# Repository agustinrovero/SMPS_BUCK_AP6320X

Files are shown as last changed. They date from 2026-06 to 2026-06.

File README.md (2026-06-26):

# Mini 2A Buck Converter SMPS (AP6320X Family)

This repository contains the hardware design files in **KiCad** for an ultra-compact, high-efficiency **2A synchronous buck (step-down) converter**. The board layout is fully compatible with all four variants of the **AP6320X** integrated circuit from Diodes Incorporated, allowing the same PCB to be populated for different switching frequencies, operating modes, and output voltages.

## Technical Specifications

* **Input Voltage Range ($V_{IN}$):** 3.8 V to 32 V
* **Continuous Output Current ($I_{OUT}$):** 2 A
* **EMI Optimization:** Features Frequency Spread Spectrum (FSS) and a proprietary gate driver system to eliminate switching node ringing without external components.
* **Form Factor:** $14.4\times15.4\text{ mm}^2$ mini-size PCB layout optimized for tight spaces and minimal current loops.

---

## IC Variant Compatibility Matrix

The base PCB accommodates any of the four chip versions. Your component selection for the feedback network ($R_1$ and $R_2$) depends entirely on the specific IC you choose to solder:

| Variant | Frequency | Light-Load Mode | Output Voltage | PCB Assembly Note |
| :--- | :--- | :--- | :--- | :--- |
| **AP63200** | 500 kHz | PFM (High Efficiency) | Adjustable (0.8 V to $V_{IN}$) | Populate feedback resistors $R_1$ and $R_2$, and capacitor $C_{f1}$ |
| **AP63201** | 500 kHz | Forced PWM | Adjustable (0.8 V to $V_{IN}$) | Populate feedback resistors $R_1$ and $R_2$, and capacitor $C_{f1}$ |
| **AP63203** | 1.1 MHz | PFM (High Efficiency) | **Fixed 3.3 V** | Solder $0\,\Omega$ jumper on $R_1$, omit $R_2$ |
| **AP63205** | 1.1 MHz | PFM (High Efficiency) | **Fixa 5.0 V** | Solder $0\,\Omega$ jumper on $R_1$, omit $R_2$ |

---

## Repository Structure

* `Hardware`: Core KiCad project files (`.kicad_pro`, `.kicad_sch`, `.kicad_pcb`).
* `Docs`: Component [datasheets](https://diodes.com) and reference application notes.
* `Outputs/3D`:
* `Outputs/BOM`: Interactive Bill of Materials (iBOM) and CSV component list.
* `Outputs/Gerbers`: Production-ready Gerber and NC Drill files.

---

## Component Specifications & Form Factor

* **Passives:** All capacitors, resistors, and LEDs utilize compact **0603** SMD packages to minimize the board footprint.
* **Power Inductor ($L_1$):** Designed with a standard **$6\times 6\text{ mm}$** footprint.
  * The default inductor handles the full 2 A output requirement.
  * For lower profile or lower current applications, alternative inductors like the **Abracon ASPI-0628-6R8M-T1** can be used (supports up to 1.5 A with a height of only 2.8 mm instead of 4.5 mm).

---

## Critical Component Selection

* **Power Inductor ($L_1$):** Shielded power inductor with a saturation current ($I_{SAT}$) rating strictly above **3 A** to prevent saturation during load transients.
* **Input/Output Capacitors ($C_{IN}$ / $C_{OUT}$):** **X7R** or **X5R** MLCC ceramic capacitors for low ESR and high capacitance retention under DC bias.
* **Feedback Resistors:** **1% tolerance** SMD resistors to maintain excellent target voltage accuracy (for adjustable versions).

---

## Requirements

* Designed and verified using **KiCad v9.0.8**.

## License

This open-source hardware project is distributed under the **CERN OHL-W v2** (CERN Open Hardware Licence Weak) or equivalent open-source standard.

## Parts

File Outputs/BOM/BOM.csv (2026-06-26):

Reference | Qty | Value | DNP | Manufacturer | MPN | RoHS | Unity Price (DigiKey, US$) | Datasheet | DigiKey | Mouser
Ca1 | 1 | 10 uF |  | Murata Electronics | GRM188R6YA106MA73D | Compliant | 0.1 | https://pim.murata.com/asset/pim4/ceramicCapacitorSMD/GRM188R6YA106MA73-01A-EN_PDF_CERAMICCAPACITORSMD | https://www.digikey.com/en/products/detail/murata-electronics/GRM188R6YA106MA73D/5877411 | https://www.mouser.com/ProductDetail/Murata-Electronics/GRM188R6YA106MA73D?qs=I53XXhTNm8uKsiF7Obn3Gg%3D%3D
Cb1,Cb2,Cb3 | 3 | 10 uF |  | Murata Electronics | GRM188Z71A106KA73D | Compliant | 0.1 | https://search.murata.co.jp/Ceramy/image/img/A01X/G101/ENG/GRM188Z71A106KA73-01A.pdf | https://www.digikey.com/en/products/detail/murata-electronics/GRM188Z71A106KA73D/13401725 | https://www.mouser.com/ProductDetail/Murata-Electronics/GRM188Z71A106KA73D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
Cd1,Cd2,Cd3,Cd4 | 4 | 100 nF |  | Samsung Electro-Mechanics | CL10B104JB8NNNC | Compliant | 0.1 | https://mm.digikey.com/Volume0/opasdata/d220001/medias/docus/609/CL10B104JB8NNNC_Spec.pdf | https://www.digikey.com/en/products/detail/samsung-electro-mechanics/CL10B104JB8NNNC/3886691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 | https://www.mouser.com/ProductDetail/Samsung-Electro-Mechanics/CL10B104JB8NNNC?qs=349EhDEZ59oLEw5wc1qvGw%3D%3D
Ce1 | 1 | 1 uF |  | Samsung Electro-Mechanics | CL10A105KB8NNNC | Compliant | 0.11 | https://mm.digikey.com/Volume0/opasdata/d220001/medias/docus/658/CL10A105KB8NNNC_Spec.pdf | https://www.digikey.com/en/products/detail/samsung-electro-mechanics/CL10A105KB8NNNC/3887518 | https://www.mouser.com/ProductDetail/Samsung-Electro-Mechanics/CL10A105KB8NNNC?qs=ktYoCbbtCSJz4pFCLWXd5g%3D%3D
D1 | 1 | LTST-C190KFKT |  | Lite-On | LTST-C190KFKT | Compliant | 0.12 | https://optoelectronics.liteon.com/upload/download/DS-22-99-0186/LTST-C190KFKT.PDF | https://www.digikey.com/en/products/detail/liteon/LTST-C190KFKT/386813 | https://www.mouser.com/ProductDetail/LITEON/LTST-C190KFKT?qs=6QHXI9jVcTyVErVIqD1vhg%3D%3D
J1 | 1 | 61300411121 | DNP | Würth Elektronik | 61300411121 | Compliant | 0.19 | https://www.we-online.com/components/products/datasheet/61300411121.pdf | https://www.digikey.com/en/products/detail/w%C3%BCrth-elektronik/61300411121/4846827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 | https://www.mouser.com/ProductDetail/Wurth-Elektronik/61300411121?qs=PhR8RmCirEYQcLLqXD8rAA%3D%3D
L1 | 1 | Abracon LLC ASPI-6045S-6R8M-T |  | Abracon LLC | ASPI-6045S-6R8M-T | Compliant | 0.4 | https://abracon.com/Magnetics/power/ASPI-6045S.pdf | https://www.digikey.com/en/products/detail/abracon-llc/ASPI-6045S-6R8M-T/2343387 | https://www.mouser.com/ProductDetail/ABRACON/ASPI-6045S-6R8M-T?qs=Y3s8Jkk9bu9mAbWIGyDq8w%3D%3D
R1 | 1 | 0 Ω |  | YAGEO | RC0603FR-070RL | Compliant | 0.1 | https://yageogroup.com/content/datasheet/asset/file/PYU-RC_GROUP_51_ROHS_L | https://www.digikey.com/en/products/detail/yageo/RC0603FR-070RL/1304008 | https://www.mouser.com/ProductDetail/YAGEO/RC0603FR-070RL?qs=0yPvnVz5%2FmpDQv43TwvCfw%3D%3D
R2 | 1 | 10 kΩ | DNP | YAGEO | RC0603FR-0710KL | Compliant | 0.1 | https://yageogroup.com/content/datasheet/asset/file/PYU-RC_GROUP_51_ROHS_L | https://www.digikey.com/en/products/detail/yageo/RC0603FR-0710KL/726880 | https://www.mouser.com/ProductDetail/YAGEO/RC0603FR-0710KL?qs=grNVn54RoB%252B3GtjbJj3wJQ%3D%3D
R3 | 1 | 1 kΩ |  | YAGEO | RC0603FR-071KL | Compliant | 0.1 | https://yageogroup.com/content/datasheet/asset/file/PYU-RC_GROUP_51_ROHS_L | https://www.digikey.com/en/products/detail/yageo/RC0603FR-071KL/726843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 | https://www.mouser.com/ProductDetail/YAGEO/RC0603FR-071KL?qs=VU8sRB4EgwApHsk4rF%2F3zg%3D%3D
R4 | 1 | 10 kΩ |  | YAGEO | RC0603FR-0710KL | Compliant | 0.1 | https://yageogroup.com/content/datasheet/asset/file/PYU-RC_GROUP_51_ROHS_L | https://www.digikey.com/en/products/detail/yageo/RC0603FR-0710KL/726880 | https://www.mouser.com/ProductDetail/YAGEO/RC0603FR-0710KL?qs=grNVn54RoB%252B3GtjbJj3wJQ%3D%3D
U1 | 1 | AP63205WU-7 |  | Diodes Incorporated | AP63205WU-7 | Compliant | 0.8 | https://www.diodes.com/assets/Datasheets/AP63200-AP63201-AP63203-AP63205.pdf | https://www.digikey.com/en/products/detail/diodes-incorporated/AP63205WU-7/9858424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 | https://www.mouser.com/ProductDetail/Diodes-Incorporated/AP63205WU-7?qs=u16ybLDytRZtkj8PzdWCOw%3D%3D
Cf1 | 1 | 100 pF | DNP | Samsung Electro-Mechanics | CL10C101JB8NNNC | Compliant | 0.1 | https://mm.digikey.com/Volume0/opasdata/d220001/medias/docus/609/CL10C101JB8NNNC_Spec.pdf | https://www.digikey.com/en/products/detail/samsung-electro-mechanics/CL10C101JB8NNNC/3886666 | https://www.mouser.com/ProductDetail/Samsung-Electro-Mechanics/CL10C101JB8NNNC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

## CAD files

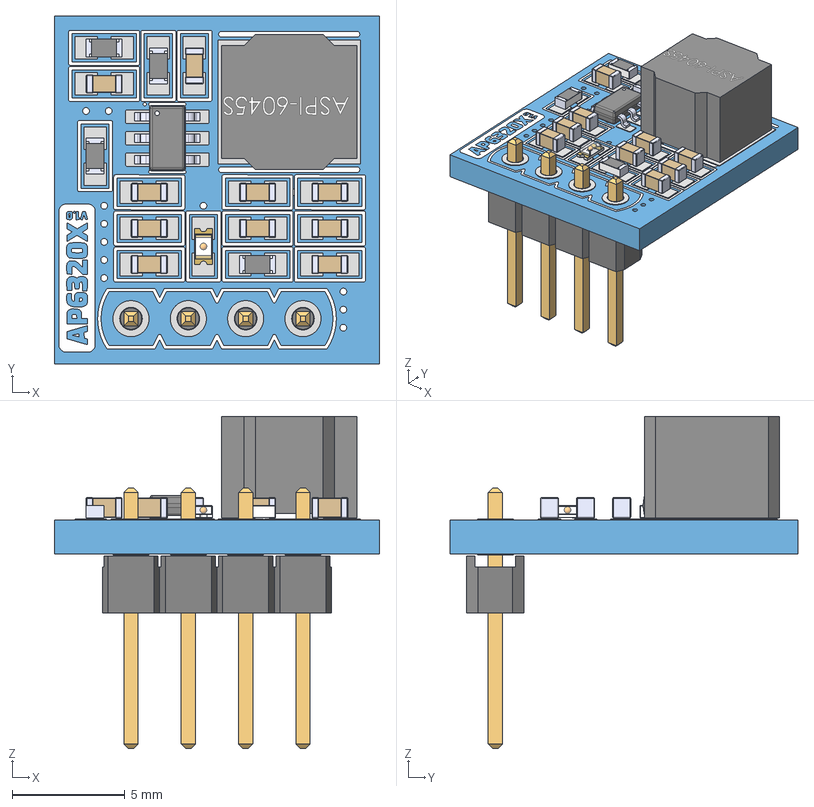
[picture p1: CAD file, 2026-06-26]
Outputs/3D/SMPS_BUCK_AP6320X.step
14.4 x 15.4 x 14.7 mm
CL10B104JB8NNNC x 10
YAGEO_RC0603FR070RL x 4
Abracon_LLC_ASPI-6045S
Light
Anode Bottom
Cathode Bottom
Anode
Cathode
Base
TSOT23-6
6130xx11121_PIN x 4
SMPS_BUCK_AP6320X_pad
SMPS_BUCK_AP6320X_silkscreen x 2
SMPS_BUCK_AP6320X_PCB

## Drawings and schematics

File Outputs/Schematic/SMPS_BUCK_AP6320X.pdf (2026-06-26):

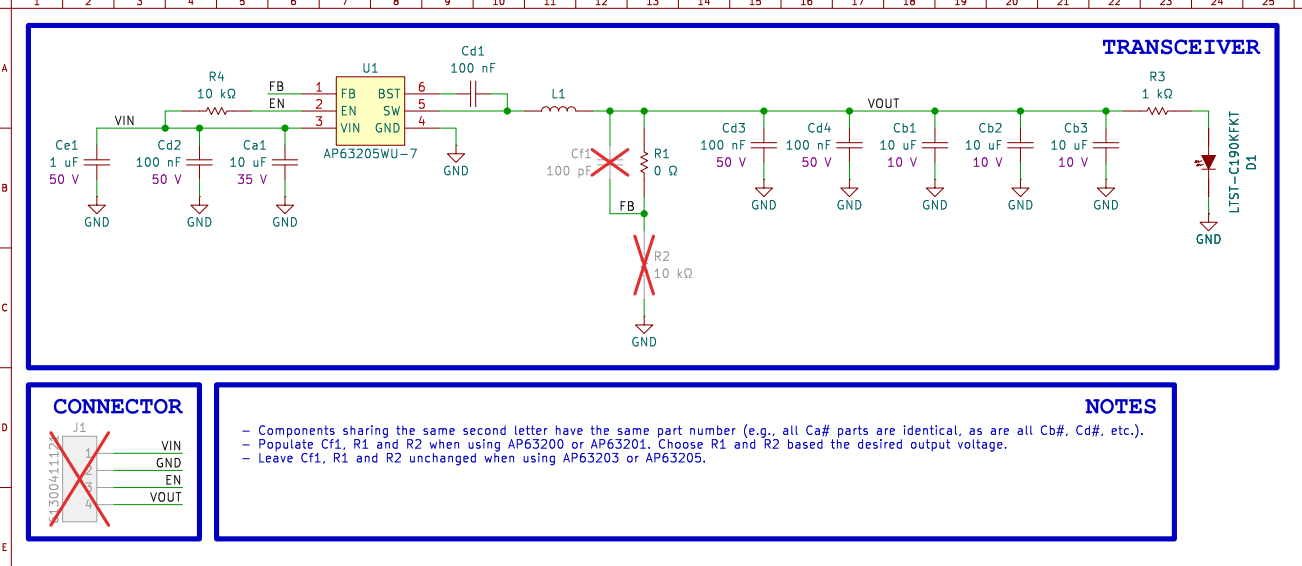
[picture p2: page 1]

File: SMPS_BUCK_AP6320X.kicad_sch Author: Agustin Rovero

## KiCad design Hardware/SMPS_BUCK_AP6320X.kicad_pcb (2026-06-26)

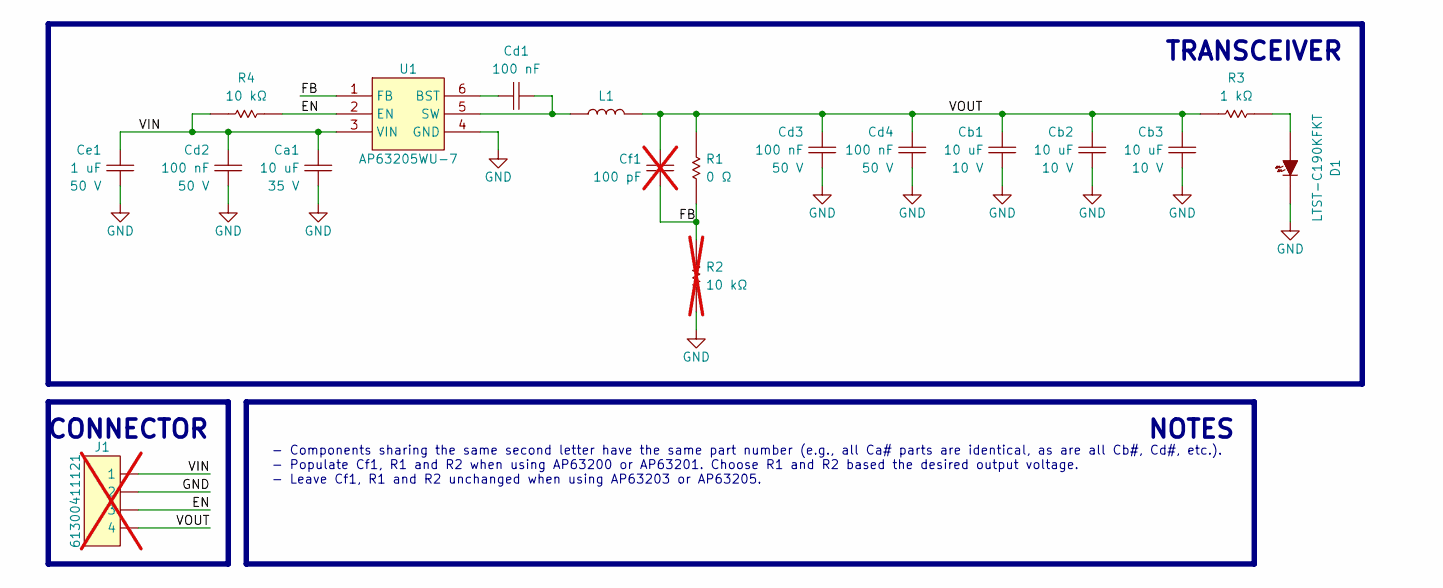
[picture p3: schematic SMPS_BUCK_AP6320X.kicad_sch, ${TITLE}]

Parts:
Ca1: 10 uF; Samsung_Electro-Mechanics_CL10B104JB8NNNC; Tolerance 20 %; Voltage 35 V; MPN GRM188R6YA106MA73D
Cb1, Cb2, Cb3: 10 uF; Samsung_Electro-Mechanics_CL10B104JB8NNNC; Tolerance 10 %; Voltage 10 V; MPN GRM188Z71A106KA73D
Cd1, Cd2, Cd3, Cd4: 100 nF; Samsung_Electro-Mechanics_CL10B104JB8NNNC; Tolerance 5 %; Voltage 50 V; MPN CL10B104JB8NNNC
Ce1: 1 uF; Samsung_Electro-Mechanics_CL10B104JB8NNNC; Tolerance 10 %; Voltage 50 V; MPN CL10A105KB8NNNC
Cf1: 100 pF; Samsung_Electro-Mechanics_CL10B104JB8NNNC; Tolerance 5 %; Voltage 50 V; MPN CL10C101JB8NNNC; not fitted
D1: LTST-C190KFKT; Lite-On_LTST-C190KFKT; MPN LTST-C190KFKT
J1: 61300411121; Würth_Elektronik_61300411121; MPN 61300411121; not fitted
L1: Abracon LLC ASPI-6045S-6R8M-T; Abracon_LLC_ASPI-6045S-6R8M-T; MPN ASPI-6045S-6R8M-T
R1: 0 Ω; YAGEO_RC0603FR-070RL; Tolerance 1 %; MPN RC0603FR-070RL
R2: 10 kΩ; YAGEO_RC0603FR-070RL; Tolerance 1 %; MPN RC0603FR-0710KL; not fitted
R3: 1 kΩ; YAGEO_RC0603FR-070RL; Tolerance 1 %; MPN RC0603FR-071KL
R4: 10 kΩ; YAGEO_RC0603FR-070RL; Tolerance 1 %; MPN RC0603FR-0710KL
U1: AP63205WU-7; TSOT23-6; MPN AP63205WU-7

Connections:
/EN: J1.3, R4.1, U1.2 (EN)
/FB: Cf1.1, R1.1, R2.2, U1.1 (FB)
/VIN: Ca1.2, Cd2.2, Ce1.2, J1.1, R4.2, U1.3 (VIN)
/VOUT: Cb1.2, Cb2.2, Cb3.2, Cd3.2, Cd4.2, Cf1.2, J1.4, L1.2, R1.2, R3.1
GND: Ca1.1, Cb1.1, Cb2.1, Cb3.1, Cd2.1, Cd3.1, Cd4.1, Ce1.1, D1.K, J1.2, R2.1, U1.4 (GND)
unnamed: D1.A, R3.2
unnamed: Cd1.1, U1.6 (BST)
unnamed: Cd1.2, L1.1, U1.5 (SW)

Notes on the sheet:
CONNECTOR
TRANSCEIVER
NOTES
- Components sharing the same second letter have the same part number (e.g., all Ca# parts are identical, as are all Cb#, Cd#, etc.). - Populate Cf1, R1 and R2 when using AP63200 or AP63201. Choose R1 and R2 based the desired output voltage. - Leave Cf1, R1 and R2 unchanged when using AP63203 or AP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

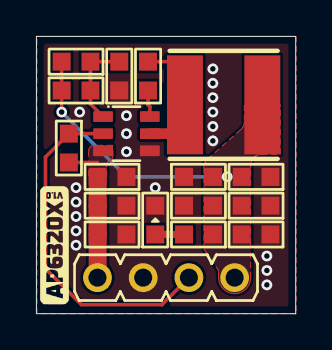
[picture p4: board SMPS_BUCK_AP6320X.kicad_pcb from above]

Board: 2 copper layers, 14.4 x 15.4 mm, 18 parts (1 on the bottom side), 8 nets.

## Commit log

2026-06-24 New layout.
    [SMPS_BUCK_AP6320X.kicad_pcb, SMPS_BUCK_AP6320X.kicad_sch]
2026-06-25 Changed inductor and layout.
    [SMPS_BUCK_AP6320X.kicad_pcb, SMPS_BUCK_AP6320X.kicad_sch]
2026-06-25 Added README file and PCB logos.
    [SMPS_BUCK_AP6320X.kicad_pcb, SMPS_BUCK_AP6320X.kicad_sch]
2026-06-25 Files are now placed into folders.
    [SMPS_BUCK_AP6320X.kicad_pcb, SMPS_BUCK_AP6320X.kicad_sch]
2026-06-26 Added BOM files, 3D and unit prices to BOM.
    [BOM.csv, SMPS_BUCK_AP6320X.kicad_pcb, SMPS_BUCK_AP6320X.kicad_sch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]
2026-06-26 Added shcematic file.
    [SMPS_BUCK_AP6320X.kicad_pcb]
